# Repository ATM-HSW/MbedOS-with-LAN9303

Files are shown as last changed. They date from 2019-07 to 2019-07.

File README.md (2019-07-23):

# LAN9303 shield for NUCLEO-144 and Mbed OS

## Introduction

BACnet/IP gateway board stack

## Hardware modification

The onboard Phy must be disabled. For this purpose, several solder bridges (0Ohm resistors) must be removed:
- from top: SB13
- from button: SB160, SB164, SB178, SB181, SB182, SB183

Snippets from the user manual UM1974 show the positions on top and bottom layer.

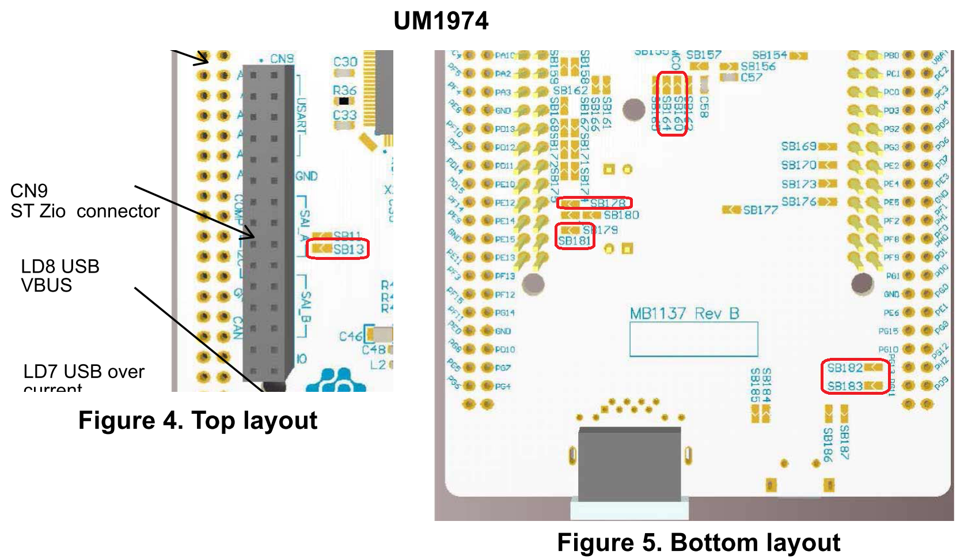
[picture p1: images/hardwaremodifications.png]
board modification


## Mbed OS integration

comming soon

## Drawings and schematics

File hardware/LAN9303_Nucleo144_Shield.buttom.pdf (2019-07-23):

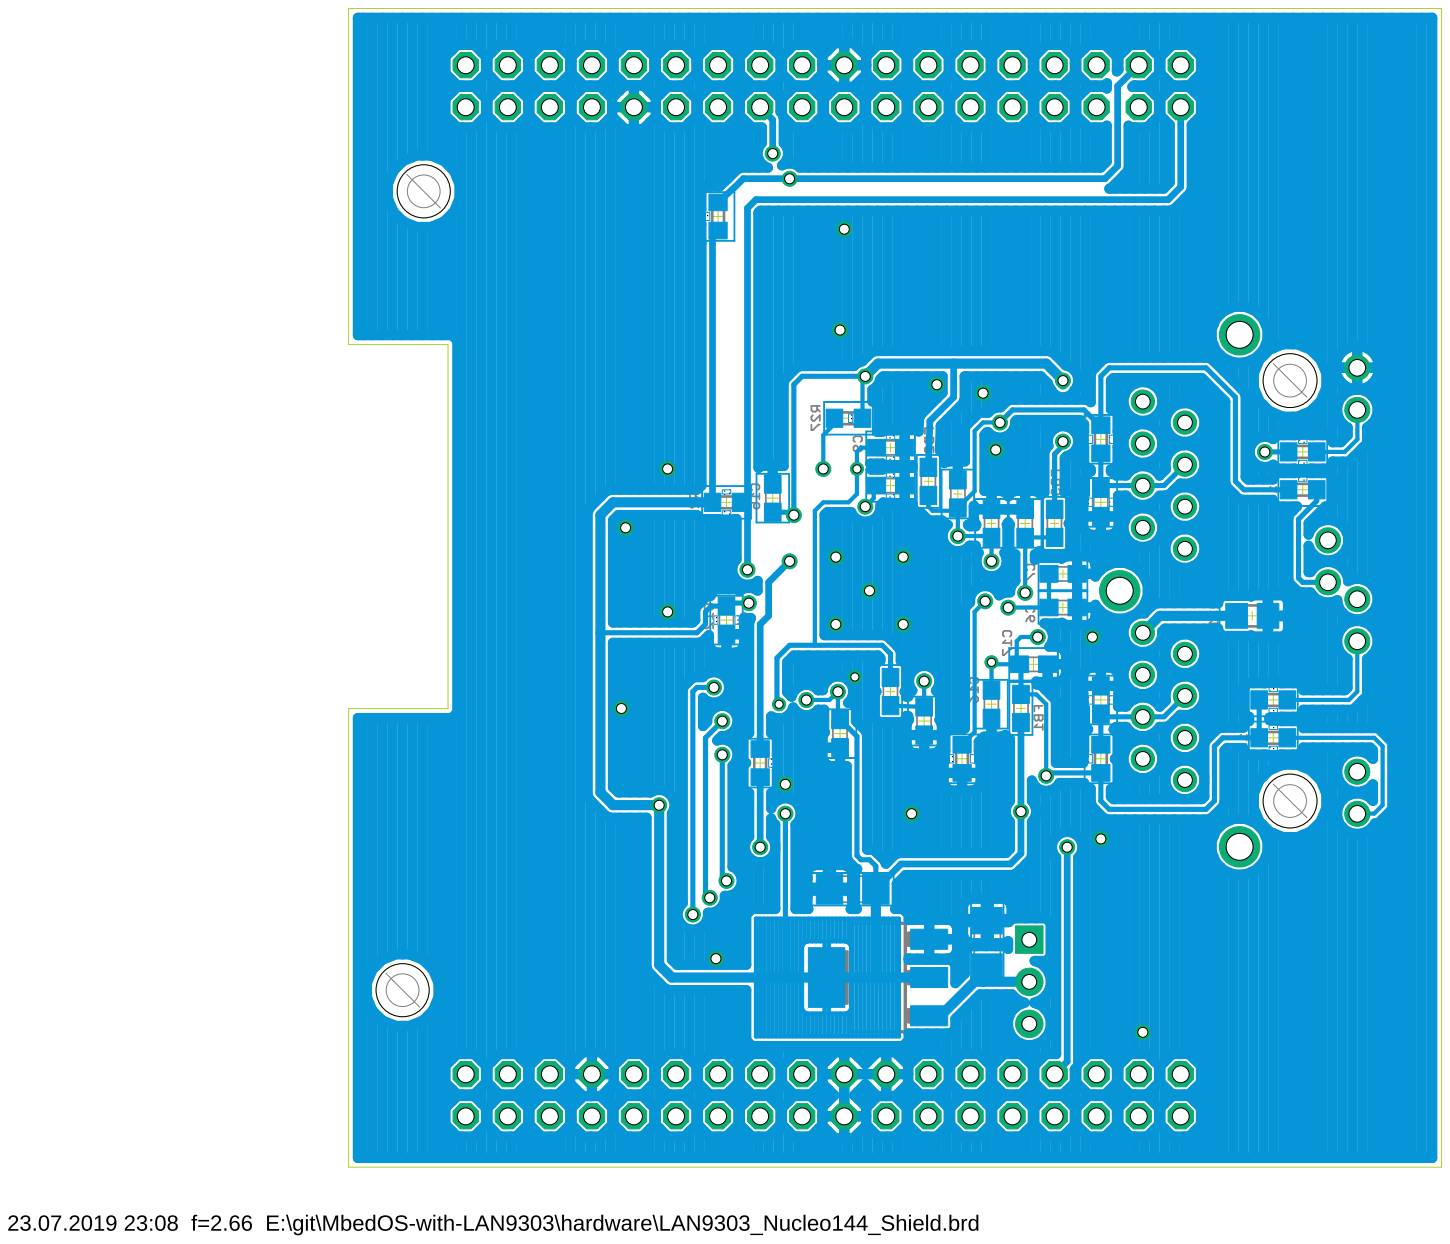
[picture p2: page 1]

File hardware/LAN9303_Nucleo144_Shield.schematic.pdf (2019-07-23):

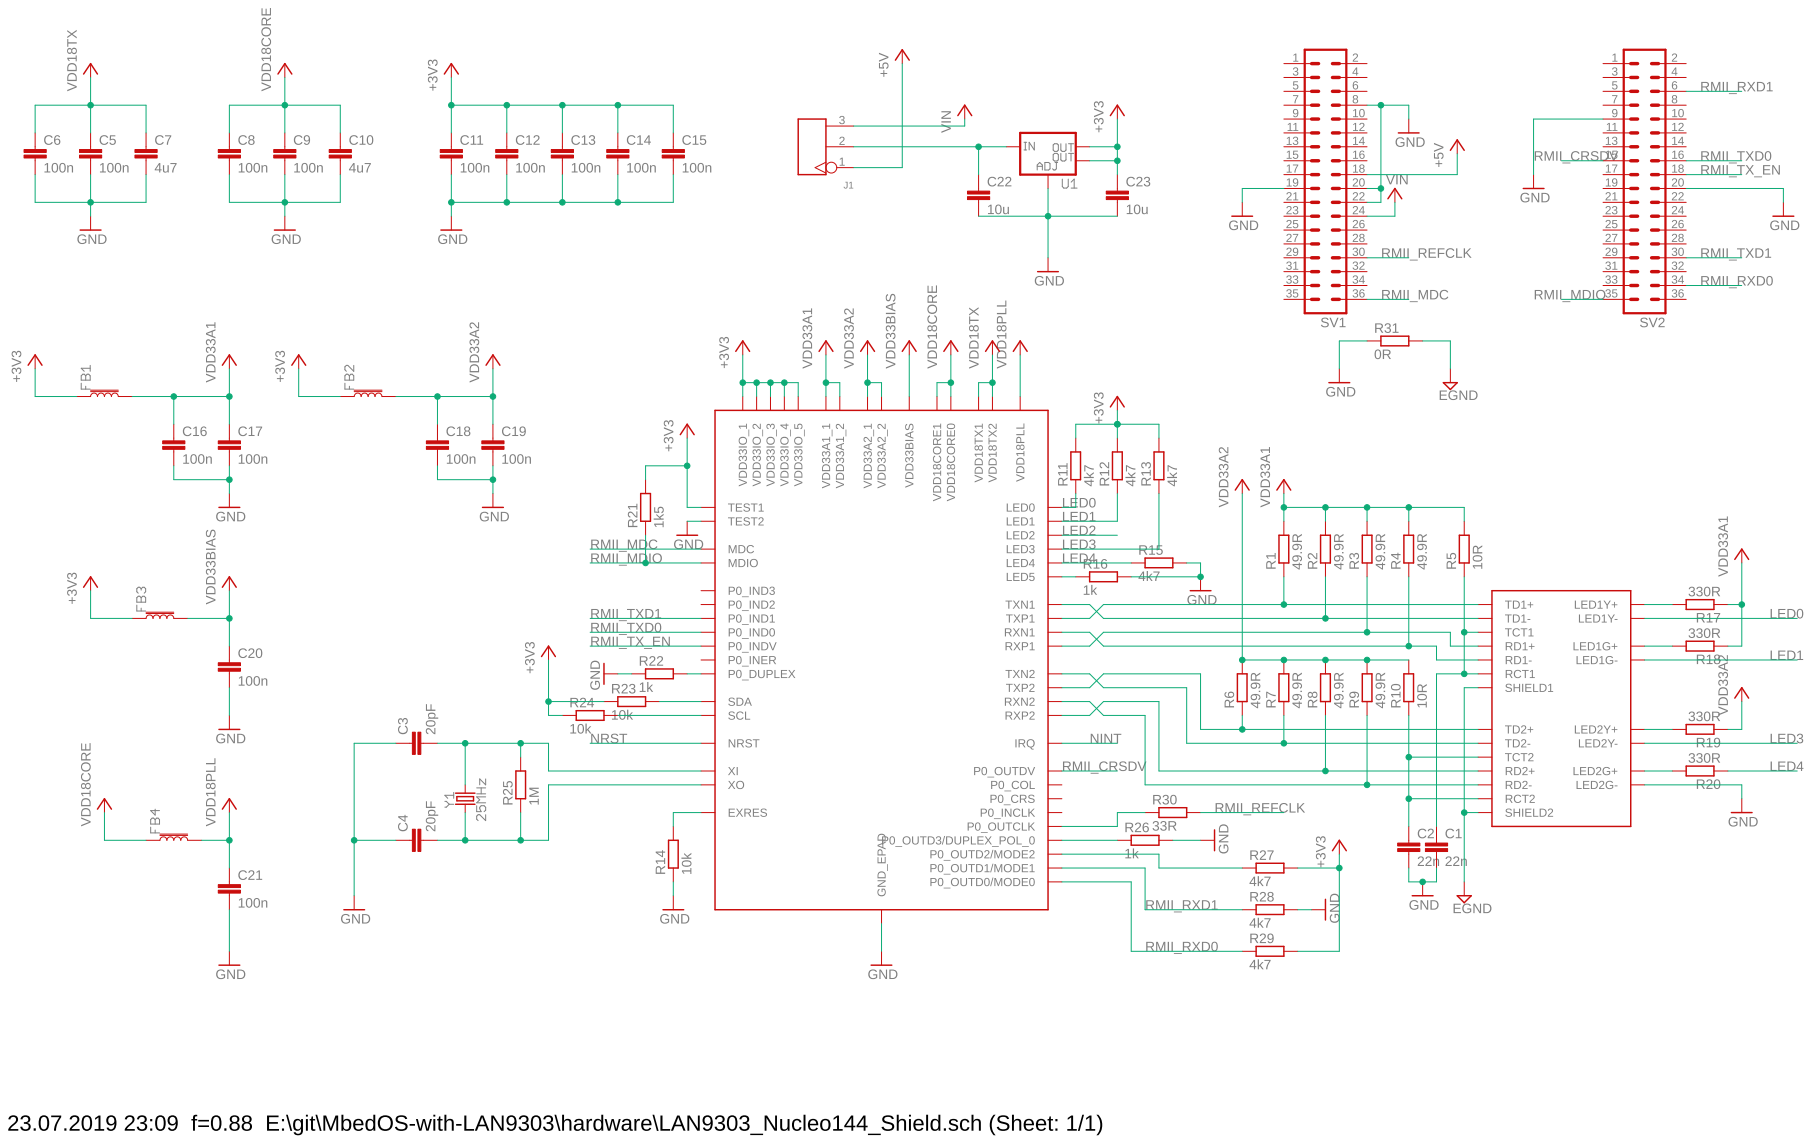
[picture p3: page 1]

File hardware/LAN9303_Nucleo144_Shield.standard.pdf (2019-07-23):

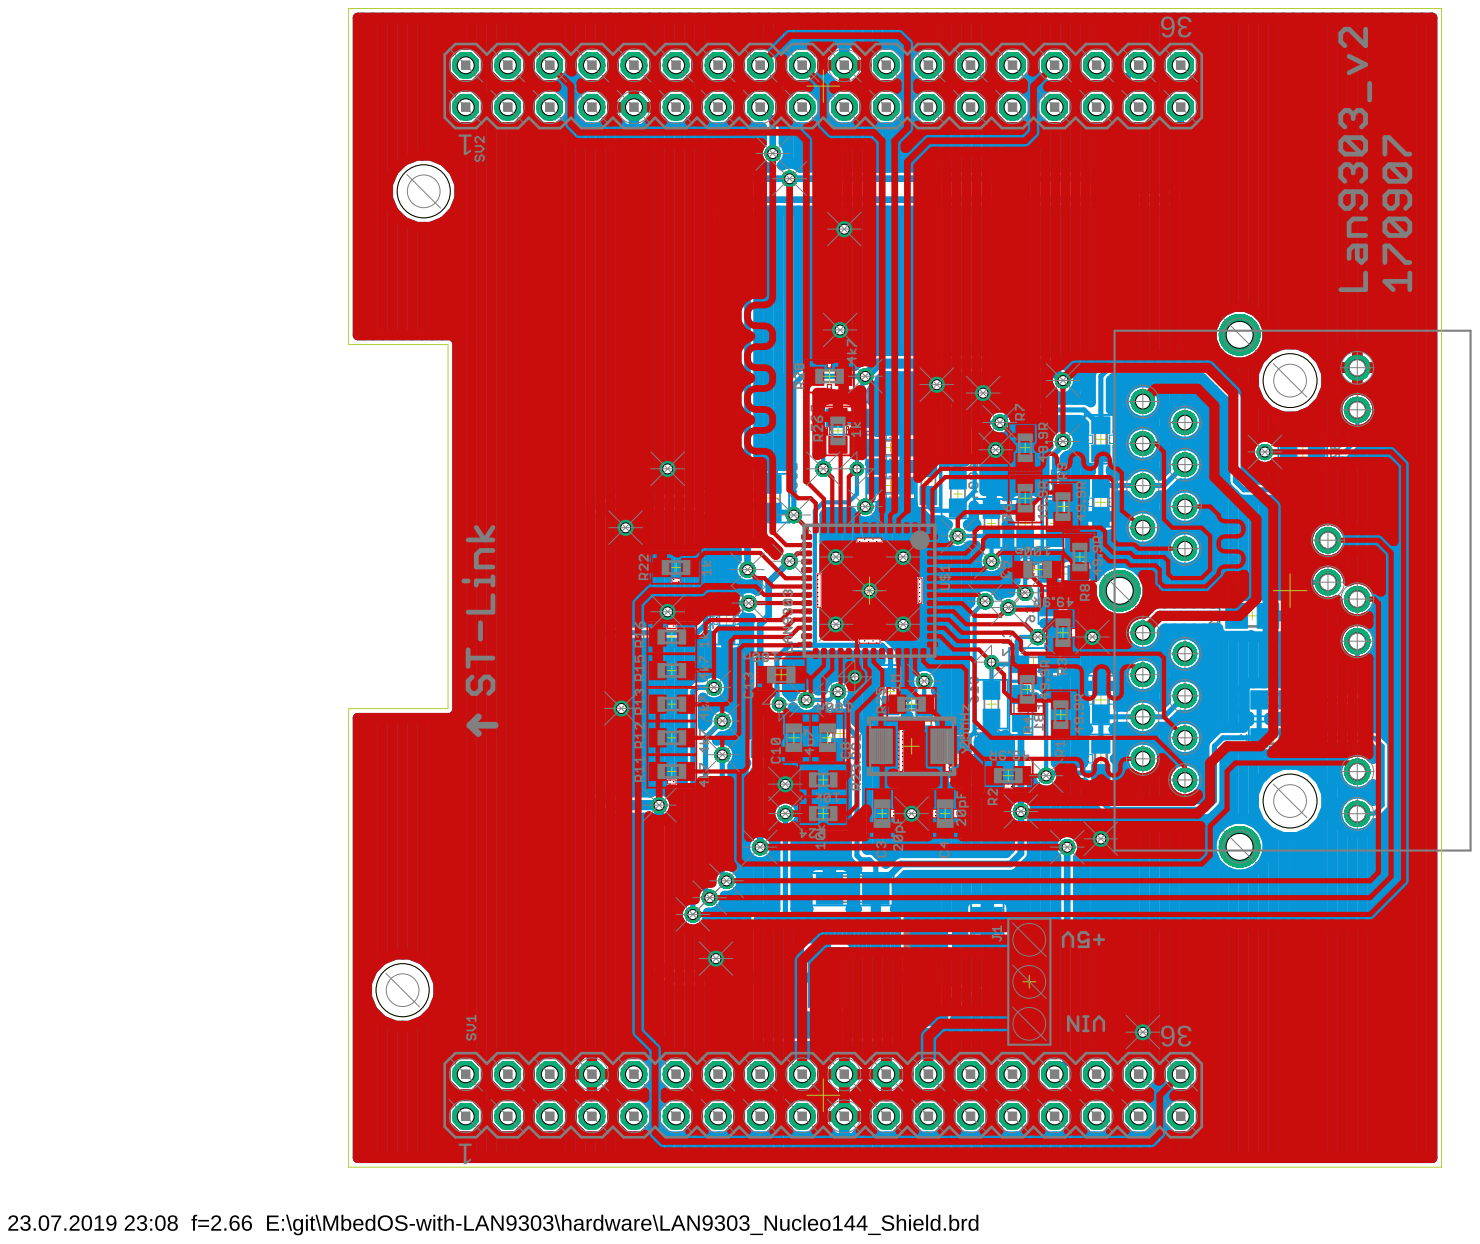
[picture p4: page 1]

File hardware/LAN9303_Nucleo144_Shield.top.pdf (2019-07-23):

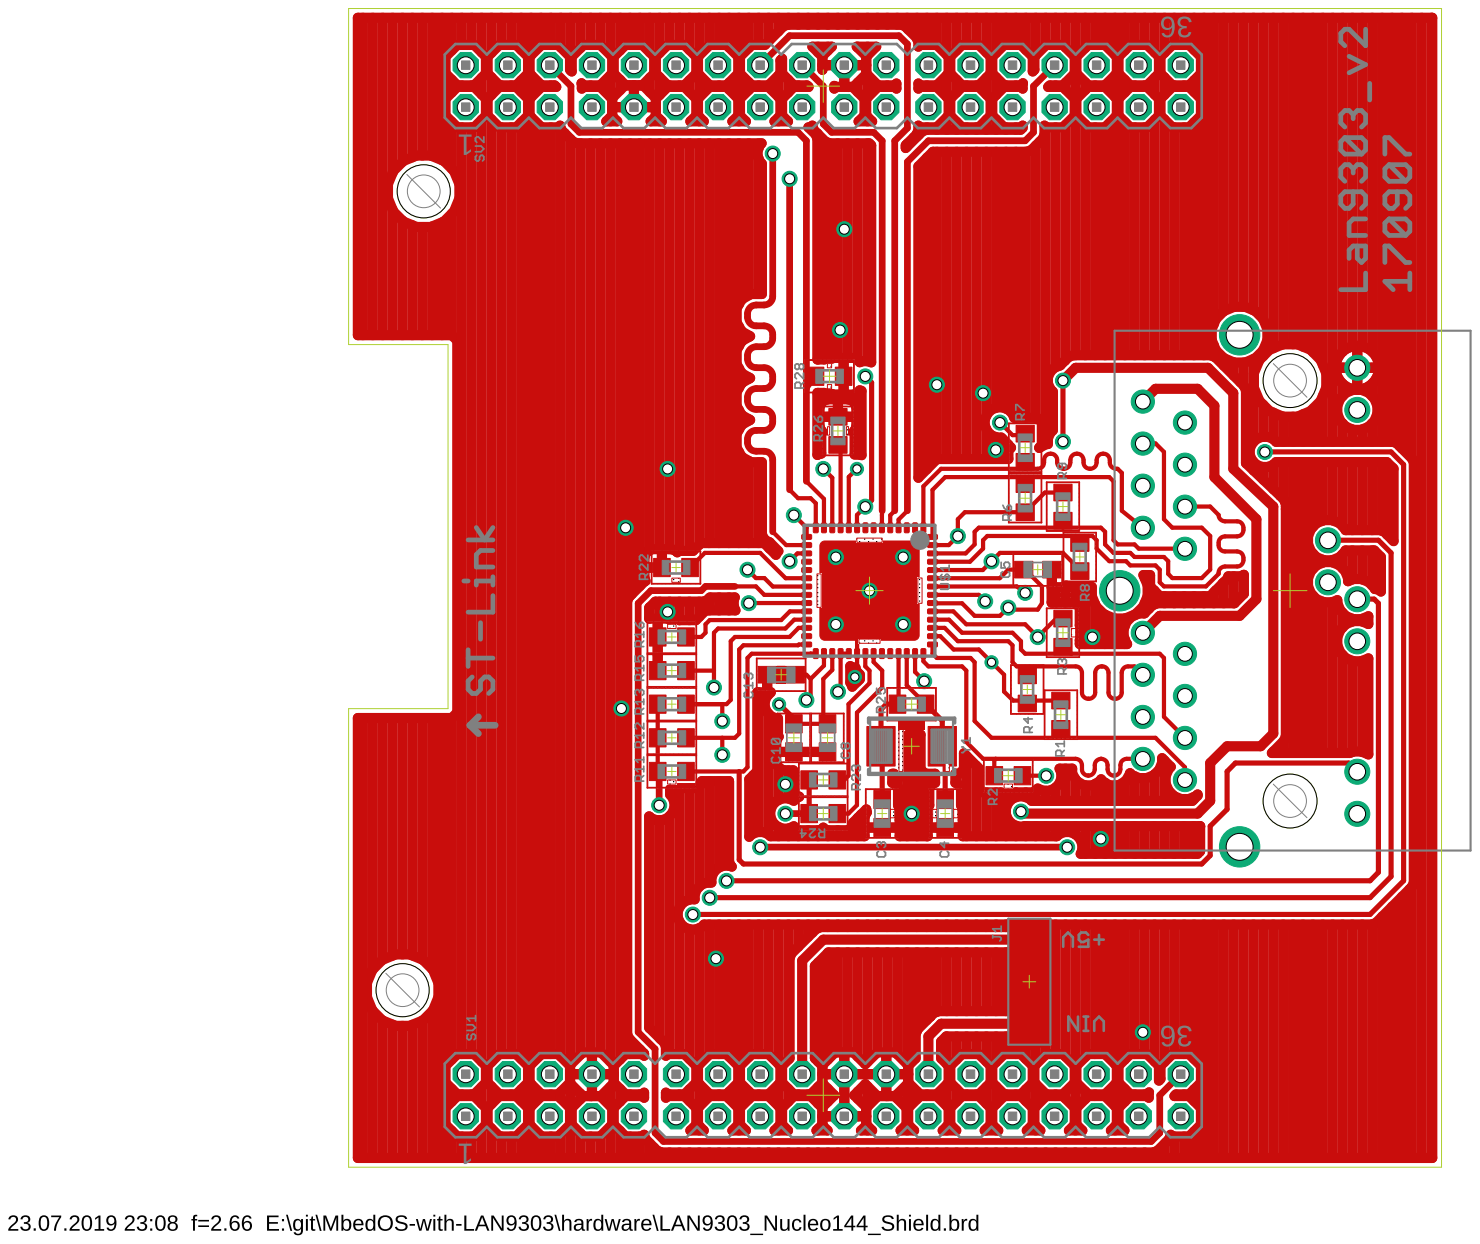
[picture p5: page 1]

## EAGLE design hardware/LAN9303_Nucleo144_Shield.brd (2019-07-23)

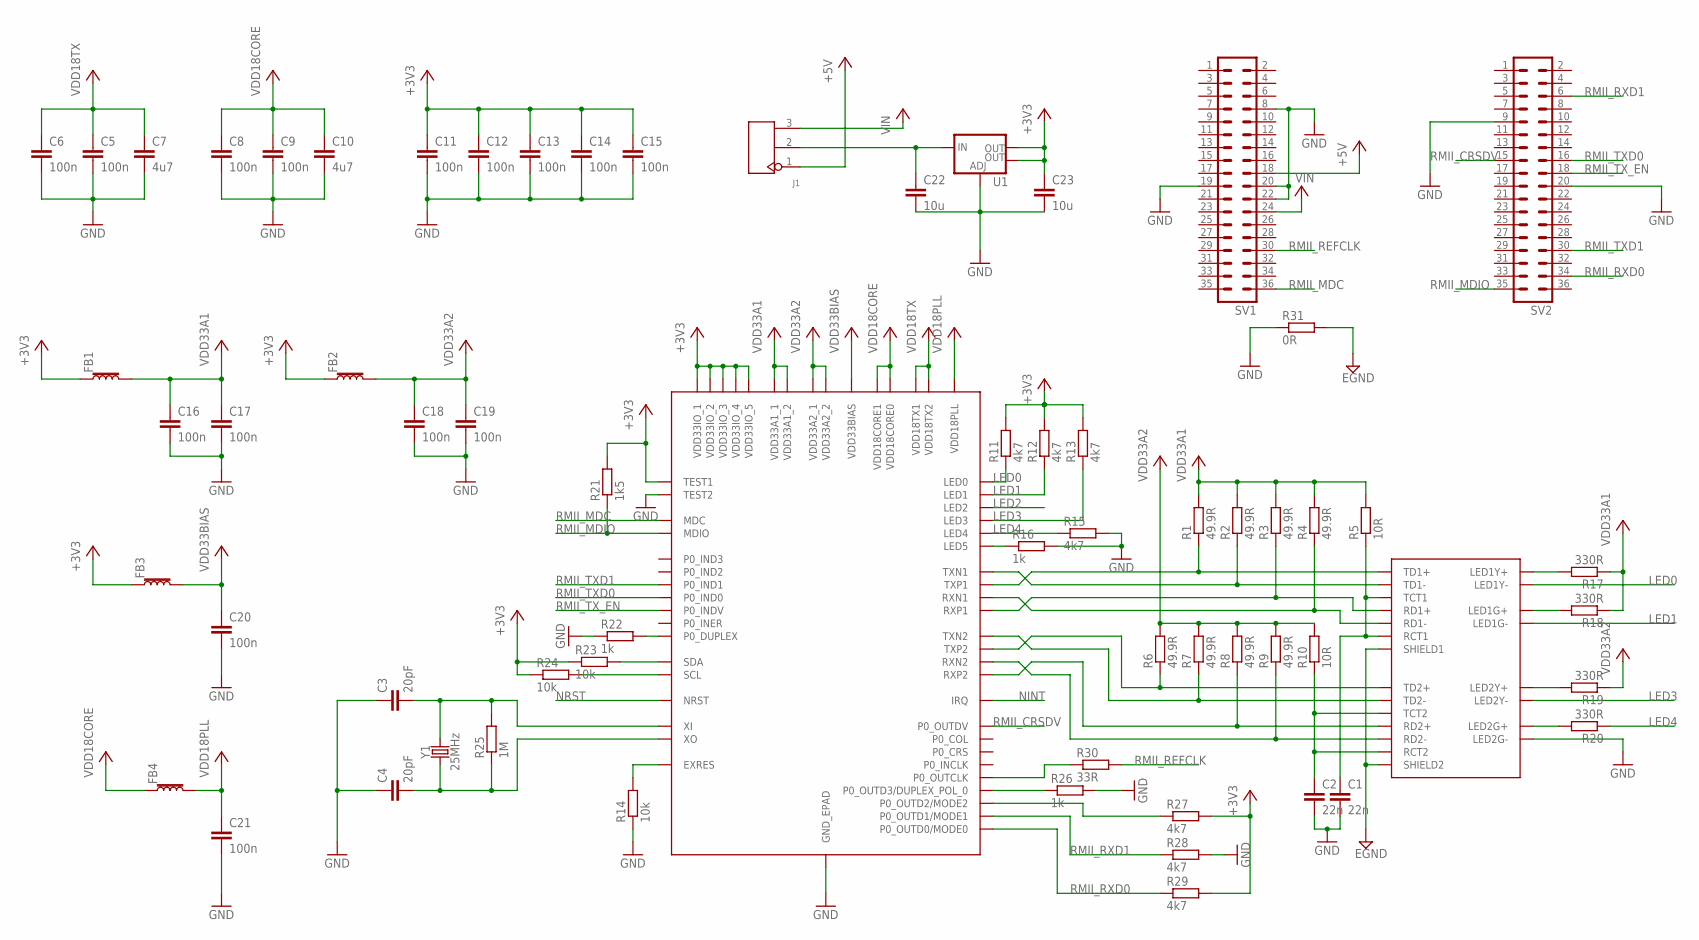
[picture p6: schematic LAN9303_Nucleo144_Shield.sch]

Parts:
C1, C2: 22n; C0603
C3, C4: 20pF; C0603
C5, C6, C8, C9, C11, C12, C13, C14, C15, C16, C17, C18, C19, C20, C21: 100n; C0603
C7, C10: 4u7; C0603
C22, C23: 10u; C1206
FB1, FB2, FB3, FB4: FERRITE_BEAD-0603; 0603
J1: DIP-BLACK-FEMALE-HEADER-VERT(3P-2.54); H3-2.54
R1, R2, R3, R4, R6, R7, R8, R9: 49.9R; R0603
R5, R10: 10R; R0603
R11, R12, R13, R15, R27, R28, R29: 4k7; R0603
R14, R23, R24: 10k; R0603
R16, R22, R26: 1k; R0603
R17, R18, R19, R20: 330R; R0603
R21: 1k5; R0603
R25: 1M; R0603
R30: 33R; R0603
R31: 0R; R0805
SV1, SV2: MA18-2
U1: V_REG_LM1117SOT223; SOT223
U$1: LAN9303; QFN56
U$2: WE_DUAL_RJ45JACK; DUAL_RJ45
Y1: 25MHz; CRYSTAL-SMD-5X3.2-2PAD

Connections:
+3V3: C11.1, C12.1, C13.1, C14.1, C15.1, C23.1, FB1.1, FB2.1, FB3.1, R11.2, R12.2, R13.2, R21.2, R23.1, R24.1, R27.2, R29.2, U1.2 (OUT), U1.4 (OUT), U$1.9 (VDD33IO_1), U$1.15 (VDD33IO_2), U$1.23 (VDD33IO_3), U$1.30 (VDD33IO_4), U$1.32 (VDD33IO_5), U$1.33 (TEST1)
+5V: J1.1, SV1.18
CLK_IN: R30.1, U$1.17 (P0_OUTCLK)
GND: C1.2, C2.2, C3.1, C4.1, C5.2, C6.2, C7.2, C8.2, C9.2, C10.2, C11.2, C12.2, C13.2, C14.2, C15.2, C16.2, C17.2, C18.2, C19.2, C20.2, C21.2, C22.2, C23.2, R14.1, R15.2, R16.2, R22.1, R26.2, R28.2, R31.1, SV1.8, SV1.19, SV1.20, SV1.22, SV2.9, SV2.20, U1.1 (ADJ), U$1.34 (TEST2), U$1.EPAD (GND_EPAD), U$2.P$2_12 (LED2G-)
GND1: R31.2, U$2.P$1_8 (SHIELD1), U$2.P$2_8 (SHIELD2)
LED0: R11.1, U$1.29 (LED0), U$2.P$1_10 (LED1Y-)
LED1: R12.1, U$1.28 (LED1), U$2.P$1_12 (LED1G-)
LED2: U$1.27 (LED2)
LED3: R13.1, U$1.26 (LED3), U$2.P$2_10 (LED2Y-)
LED4: R15.1, R20.1, U$1.25 (LED4)
unnamed: C2.1, R10.1, U$2.P$2_4 (TCT2), U$2.P$2_5 (RCT2)
unnamed: C1.1, R5.1, U$2.P$1_4 (TCT1), U$2.P$1_5 (RCT1)
unnamed: R22.2, U$1.20 (P0_DUPLEX)
unnamed: R16.1, U$1.24 (LED5)
unnamed: R17.2, U$2.P$1_9 (LED1Y+)
unnamed: R19.2, U$2.P$2_9 (LED2Y+)
unnamed: R20.2, U$2.P$2_11 (LED2G+)
unnamed: R18.2, U$2.P$1_11 (LED1G+)
unnamed: R23.2, U$1.35 (SDA)
unnamed: R24.2, U$1.36 (SCL)
unnamed: R14.2, U$1.49 (EXRES)
unnamed: R27.1, U$1.12 (P0_OUTD2/MODE2)
unnamed: C22.1, J1.2, U1.3 (IN)
unnamed: C3.2, R25.2, U$1.39 (XI), Y1.P$2 (2)
unnamed: C4.2, R25.1, U$1.40 (XO), Y1.P$1 (1)
unnamed: R26.1, U$1.11 (P0_OUTD3/DUPLEX_POL_0)
NINT: U$1.38 (IRQ)
NRST: U$1.37 (NRST)
RMII_CRSDV: SV2.15, U$1.16 (P0_OUTDV)
RMII_MDC: SV1.36, U$1.22 (MDC)
RMII_MDIO: R21.1, SV2.35, U$1.21 (MDIO)
RMII_REFCLK: R30.2, SV1.30
RMII_RXD0: R29.1, SV2.34, U$1.14 (P0_OUTD0/MODE0)
RMII_RXD1: R28.1, SV2.6, U$1.13 (P0_OUTD1/MODE1)
RMII_TXD0: SV2.16, U$1.5 (P0_IND0)
RMII_TXD1: SV2.30, U$1.4 (P0_IND1)
RMII_TX_EN: SV2.18, U$1.6 (P0_INDV)
RXN1: R4.1, U$1.45 (RXN1), U$2.P$1_6 (RD1-)
RXN2: R9.1, U$1.54 (RXN2), U$2.P$2_6 (RD2-)
RXP1: R3.1, U$1.46 (RXP1), U$2.P$1_3 (RD1+)
RXP2: R8.1, U$1.53 (RXP2), U$2.P$2_3 (RD2+)
TXN1: R2.1, U$1.42 (TXN1), U$2.P$1_2 (TD1-)
TXN2: R7.1, U$1.1 (TXN2), U$2.P$2_2 (TD2-)
TXP1: R1.1, U$1.43 (TXP1), U$2.P$1_1 (TD1+)
TXP2: R6.1, U$1.56 (TXP2), U$2.P$2_1 (TD2+)
VDD18CORE: C8.1, C9.1, C10.1, FB4.1, U$1.10 (VDD18CORE0), U$1.31 (VDD18CORE1)
VDD18PLL: C21.1, FB4.2, U$1.41 (VDD18PLL)
VDD18TX: C5.1, C6.1, C7.1, U$1.48 (VDD18TX1), U$1.51 (VDD18TX2)
VDD33A1: C16.1, C17.1, FB1.2, R1.2, R2.2, R3.2, R4.2, R5.2, R17.1, R18.1, U$1.44 (VDD33A1_1), U$1.47 (VDD33A1_2)
VDD33A2: C18.1, C19.1, FB2.2, R6.2, R7.2, R8.2, R9.2, R10.2, R19.1, U$1.52 (VDD33A2_1), U$1.55 (VDD33A2_2)
VDD33BIAS: C20.1, FB3.2, U$1.50 (VDD33BIAS)
VIN: J1.3, SV1.24

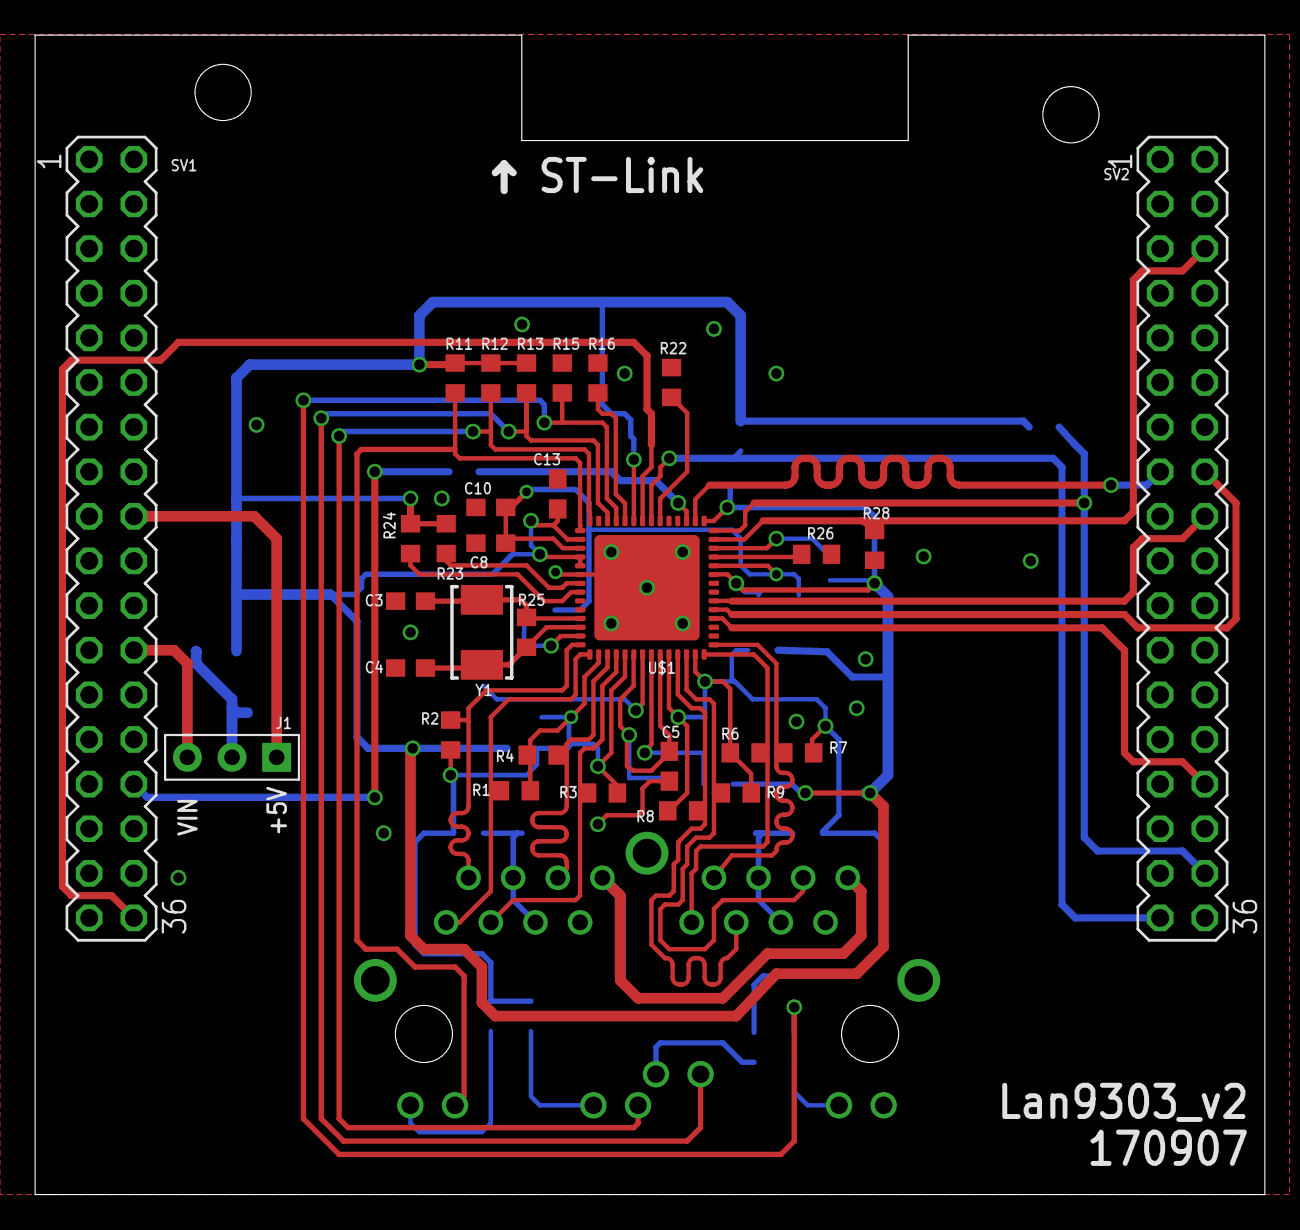
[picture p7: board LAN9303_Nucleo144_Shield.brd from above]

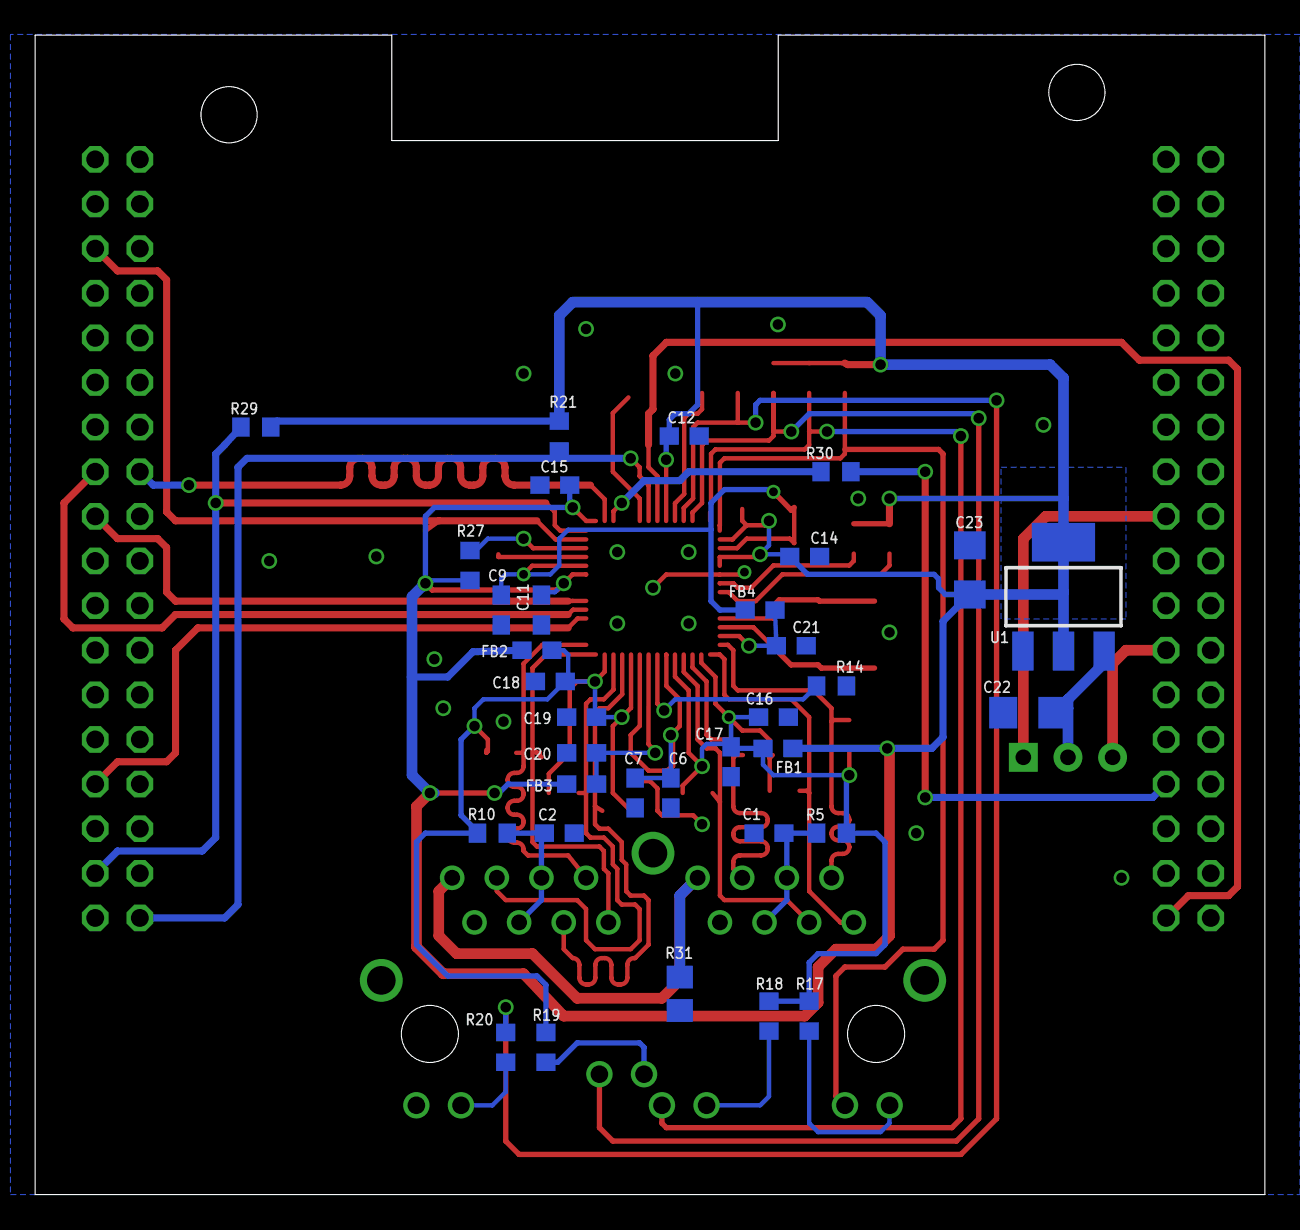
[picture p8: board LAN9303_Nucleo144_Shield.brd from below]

Board: 2 copper layers, 70.0 x 66.0 mm, 65 parts (34 on the bottom side), 49 nets.

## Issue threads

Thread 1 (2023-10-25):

Interested in your project STM32 + LAN9303 daisychain

RickerStem, 2023-10-25:
Hi!

Great project!

I found your project here (https://github.com/ARMmbed/mbed-os/issues/6775#issuecomment-386625964) I'm looking into STM32 +LAN9303 + Lwip and daisychaining for a hobby project to learn about embedded switches. Had some good results with lwip and the lan8720. But im struggling with the setup and daisy chaining part of the lan9303.

I was wondering if you where willing to share the final result?

Best regards,
Rick

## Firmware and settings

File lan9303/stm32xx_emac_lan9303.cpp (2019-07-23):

#include <stdlib.h>

#include "cmsis_os.h"

#include "mbed_interface.h"
#include "mbed_assert.h"
#include "mbed_shared_queues.h"
#include "netsocket/nsapi_types.h"

#include "stm32xx_emac_config.h"
#include "stm32xx_emac.h"

/* \brief Flags for worker thread */
#define FLAG_RX                 1

/** \brief  Driver thread priority */
#define THREAD_PRIORITY         (osPriorityHigh)

#define PHY_TASK_PERIOD_MS      200
#define ETH_ARCH_PHY_ADDRESS    (0x00)

#define STM_HWADDR_SIZE         (6)
#define STM_ETH_MTU_SIZE        1500

#if defined(DGW_NETIF_NAME)
	#define STM_ETH_IF_NAME   DGW_NETIF_NAME
#else
  #define STM_ETH_IF_NAME   "st"
#endif


#if defined (__ICCARM__)   /*!< IAR Compiler */
#pragma data_alignment=4
#endif
__ALIGN_BEGIN ETH_DMADescTypeDef DMARxDscrTab[ETH_RXBUFNB] __ALIGN_END; /* Ethernet Rx DMA Descriptor */

#if defined (__ICCARM__)   /*!< IAR Compiler */
#pragma data_alignment=4
#endif
__ALIGN_BEGIN ETH_DMADescTypeDef DMATxDscrTab[ETH_TXBUFNB] __ALIGN_END; /* Ethernet Tx DMA Descriptor */

#if defined (__ICCARM__)   /*!< IAR Compiler */
#pragma data_alignment=4
#endif
__ALIGN_BEGIN uint8_t Rx_Buff[ETH_RXBUFNB][ETH_RX_BUF_SIZE] __ALIGN_END; /* Ethernet Receive Buffer */

#if defined (__ICCARM__)   /*!< IAR Compiler */
#pragma data_alignment=4
#endif
__ALIGN_BEGIN uint8_t Tx_Buff[ETH_TXBUFNB][ETH_TX_BUF_SIZE] __ALIGN_END; /* Ethernet Transmit Buffer */

__weak uint8_t mbed_otp_mac_address(char *mac);
void mbed_default_mac_address(char *mac);

/* prototypes */
uint8_t mbed_otp_mac_address(char *mac);


#ifdef __cplusplus
extern "C" {
#endif

void _eth_config_mac(ETH_HandleTypeDef *heth);
void HAL_ETH_RxCpltCallback(ETH_HandleTypeDef *heth);
void ETH_IRQHandler(void);

#ifdef __cplusplus
}
#endif

/**
 * Ethernet Rx Transfer completed callback
 *
 * @param  heth: ETH handle
 * @retval None
 */
void HAL_ETH_RxCpltCallback(ETH_HandleTypeDef *heth)
{
    STM32_EMAC &emac = STM32_EMAC::get_instance();
    if (emac.thread) {
        osThreadFlagsSet(emac.thread, FLAG_RX);
    }
}

/**
 * Ethernet IRQ Handler
 *
 * @param  None
 * @retval None
 */
void ETH_IRQHandler(void)
{
    STM32_EMAC &emac = STM32_EMAC::get_instance();
    HAL_ETH_IRQHandler(&emac.EthHandle);
}

STM32_EMAC::STM32_EMAC()
    : thread(0)
{
}

static osThreadId_t create_new_thread(const char *threadName, void (*thread)(void *arg), void *arg, int stacksize, osPriority_t priority, os_thread_t *thread_cb)
{
    osThreadAttr_t attr = {0};
    attr.name = threadName;
    attr.stack_mem  = malloc(stacksize);
    attr.cb_mem  = thread_cb;
    attr.stack_size = stacksize;
    attr.cb_size = sizeof(os_thread_t);
    attr.priority = priority;
    return osThreadNew(thread, arg, &attr);
}

/**
 * In this function, the hardware should be initialized.
 */
bool STM32_EMAC::low_level_init_successful()
{
    /* Init ETH */
    uint8_t MACAddr[6];
    EthHandle.Instance = ETH;
    
    #if USE_LAN9303
      EthHandle.Init.AutoNegotiation = ETH_AUTONEGOTIATION_DISABLE;
    #else
      EthHandle.Init.AutoNegotiation = ETH_AUTONEGOTIATION_ENABLE;
    #endif
    
    EthHandle.Init.Speed = ETH_SPEED_100M;
    EthHandle.Init.DuplexMode = ETH_MODE_FULLDUPLEX;
    EthHandle.Init.PhyAddress = ETH_ARCH_PHY_ADDRESS;
#if (MBED_MAC_ADDRESS_SUM != MBED_MAC_ADDR_INTERFACE)
    MACAddr[0] = MBED_MAC_ADDR_0;
    MACAddr[1] = MBED_MAC_ADDR_1;
    MACAddr[2] = MBED_MAC_ADDR_2;
    MACAddr[3] = MBED_MAC_ADDR_3;
    MACAddr[4] = MBED_MAC_ADDR_4;
    MACAddr[5] = MBED_MAC_ADDR_5;
#else
    mbed_mac_address((char *)MACAddr);
#endif
    EthHandle.Init.MACAddr = &MACAddr[0];
    EthHandle.Init.RxMode = ETH_RXINTERRUPT_MODE;
    EthHandle.Init.ChecksumMode = ETH_CHECKSUM_BY_SOFTWARE;
    EthHandle.Init.MediaInterface = ETH_MEDIA_INTERFACE_RMII;
    HAL_ETH_Init(&EthHandle);

    /* Initialize Tx Descriptors list: Chain Mode */
    HAL_ETH_DMATxDescListInit(&EthHandle, DMATxDscrTab, &Tx_Buff[0][0], ETH_TXBUFNB);

    /* Initialize Rx Descriptors list: Chain Mode  */
    HAL_ETH_DMARxDescListInit(&EthHandle, DMARxDscrTab, &Rx_Buff[0][0], ETH_RXBUFNB);

    /* Configure MAC */
    _eth_config_mac(&EthHandle);

    /* Enable MAC and DMA transmission and reception */
    HAL_ETH_Start(&EthHandle);

    return true;
}

/**
 * This function should do the actual transmission of the packet. The packet is
 * contained in the memory buffer chain that is passed to the function.
 *
 * @param buf the MAC packet to send (e.g. IP packet including MAC addresses and type)
 * @return true if the packet could be sent
 *         false value if the packet couldn't be sent
 *
 * @note Returning ERR_MEM here if a DMA queue of your MAC is full can lead to
 *       strange results. You might consider waiting for space in the DMA queue
 *       to become availale since the stack doesn't retry to send a packet
 *       dropped because of memory failure (except for the TCP timers).
 */
bool STM32_EMAC::link_out(emac_mem_buf_t *buf)
{
    bool success;
    emac_mem_buf_t *q;
    uint8_t *buffer = reinterpret_cast<uint8_t *>(EthHandle.TxDesc->Buffer1Addr);
    __IO ETH_DMADescTypeDef *DmaTxDesc;
    uint32_t framelength = 0;
    uint32_t bufferoffset = 0;
    uint32_t byteslefttocopy = 0;
    uint32_t payloadoffset = 0;
    DmaTxDesc = EthHandle.TxDesc;

    /* Get exclusive access */
    TXLockMutex.lock();

    /* copy frame from pbufs to driver buffers */
    for (q = buf; q != NULL; q = memory_manager->get_next(q)) {
        /* Is this buffer available? If not, goto error */
        if ((DmaTxDesc->Status & ETH_DMATXDESC_OWN) != (uint32_t)RESET) {
            success = false;
            goto error;
        }

        /* Get bytes in current lwIP buffer */
        byteslefttocopy = memory_manager->get_len(q);
        payloadoffset = 0;

        /* Check if the length of data to copy is bigger than Tx buffer size*/
        while ((byteslefttocopy + bufferoffset) > ETH_TX_BUF_SIZE) {
            /* Copy data to Tx buffer*/
            memcpy(static_cast<uint8_t *>(buffer) + bufferoffset, static_cast<uint8_t *>(memory_manager->get_ptr(q)) + payloadoffset, (ETH_TX_BUF_SIZE - bufferoffset));

            /* Point to next descriptor */
            DmaTxDesc = reinterpret_cast<ETH_DMADescTypeDef *>(DmaTxDesc->Buffer2NextDescAddr);

            /* Check if the buffer is available */
            if ((DmaTxDesc->Status & ETH_DMATXDESC_OWN) != (uint32_t)RESET) {
                success = false;
                goto error;
            }

            buffer = reinterpret_cast<uint8_t *>(DmaTxDesc->Buffer1Addr);

            byteslefttocopy = byteslefttocopy - (ETH_TX_BUF_SIZE - bufferoffset);
            payloadoffset = payloadoffset + (ETH_TX_BUF_SIZE - bufferoffset);
            framelength = framelength + (ETH_TX_BUF_SIZE - bufferoffset);
            bufferoffset = 0;
        }
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

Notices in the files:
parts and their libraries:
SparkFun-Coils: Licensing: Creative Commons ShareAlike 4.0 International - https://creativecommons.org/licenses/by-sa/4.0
